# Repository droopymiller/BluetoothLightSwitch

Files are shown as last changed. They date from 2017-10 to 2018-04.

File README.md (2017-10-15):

# BluetoothLightSwitch
This project includes code and a schematic to make a bluetooth opperated light switch.
It accomplishes this using the Arduino Nano and HM-10

Because the HM-10 I had was actually a CC41-A, the "BRK" pin doesn't exist.
This lead me to connect the bluetooth module's VCC to an output on the Arduino so that it could be power cycled in order to disconnect clients

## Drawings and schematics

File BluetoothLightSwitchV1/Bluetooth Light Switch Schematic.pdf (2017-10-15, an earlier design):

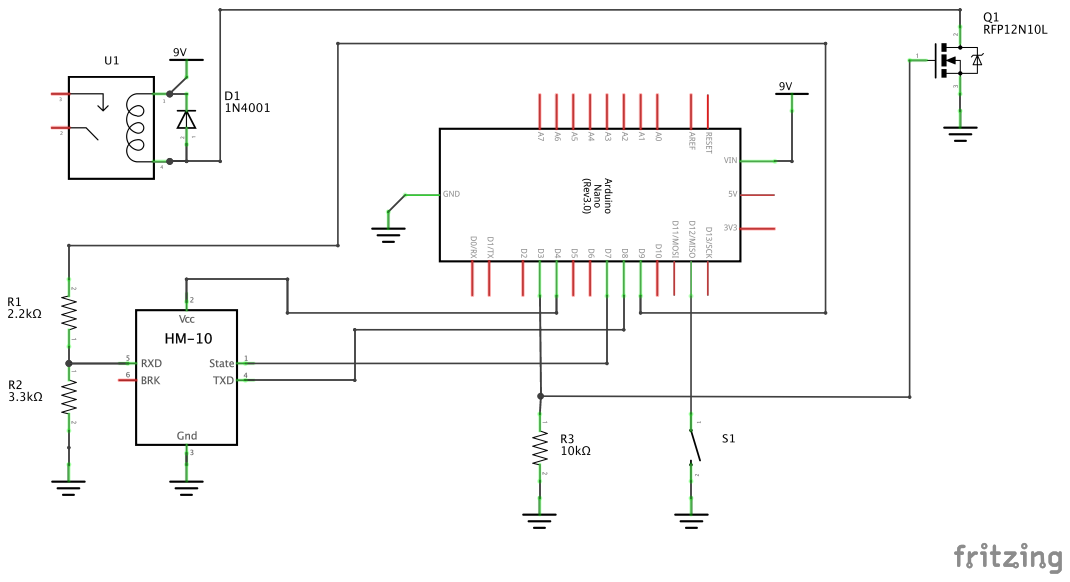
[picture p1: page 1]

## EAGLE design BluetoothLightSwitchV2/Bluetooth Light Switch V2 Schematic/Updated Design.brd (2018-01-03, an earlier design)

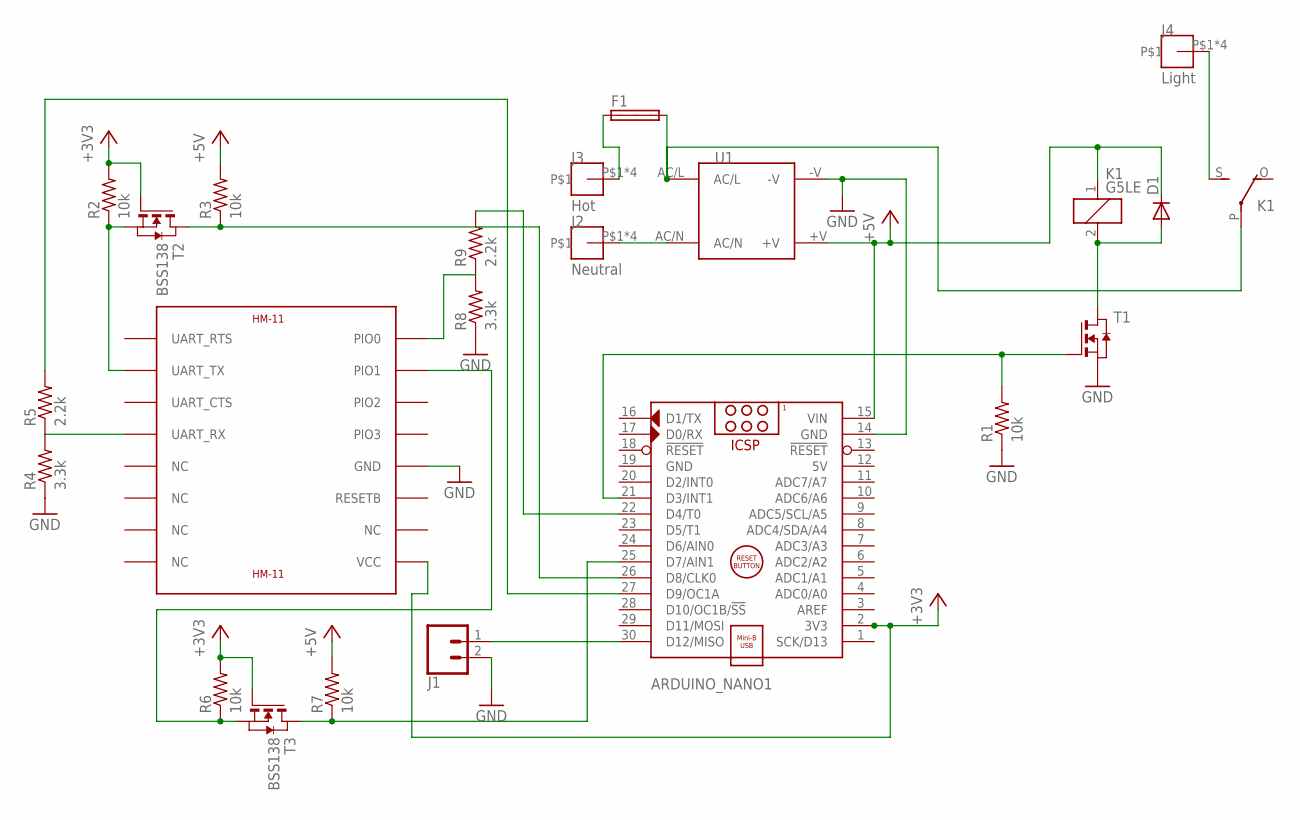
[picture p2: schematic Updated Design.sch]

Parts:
ARDUINO_NANO1: ARDUINO_NANO
D1: DIODE-SOD80C; SOD80C
F1: SHK20L
J1: CONN_025MM; SCREWTERMINAL-5MM-2
J2: Neutral; 7700
J3: Hot; 7700
J4: Light; 7700
K1: G5LE
R1, R2, R3, R6, R7: 10k; R0603
R4, R8: 3.3k; R0603
R5, R9: 2.2k; R0603
T1: NMOSSOT23; SOT-23
T2, T3: BSS138; SOT-23
U1: IRM-05-5; IRM-05
U$1: HM-11

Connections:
5V: ARDUINO_NANO1.12 (5V)
+3V3: ARDUINO_NANO1.2 (3V3), R2.2, R6.2, T2.3 (G), T3.3 (G), U$1.VCC
+5V: ARDUINO_NANO1.15 (VIN), D1.C, K1.1, R3.2, R7.2, U1.+V
GND: ARDUINO_NANO1.14 (GND), ARDUINO_NANO1.19 (GND), J1.2, U1.-V, U$1.GND
unnamed: ARDUINO_NANO1.30 (D12/MISO), J1.1
unnamed: R4.2, U$1.UART_RX
unnamed: ARDUINO_NANO1.21 (D3/INT1), T1.3 (G)
unnamed: F1.2A, K1.P, U1.AC/L
unnamed: J2.P$1, J2.P$2, J2.P$3, J2.P$4, U1.AC/N
unnamed: J4.P$1, J4.P$2, J4.P$3, J4.P$4, K1.S
unnamed: ARDUINO_NANO1.27 (D9/OC1A), R5.2
unnamed: D1.A, K1.2, T1.1 (D)
unnamed: R2.1, T2.2 (S), U$1.UART_TX
unnamed: ARDUINO_NANO1.26 (D8/CLK0), R3.1, T2.1 (D)
unnamed: R6.1, T3.2 (S), U$1.PIO1
unnamed: ARDUINO_NANO1.25 (D7/AIN1), R7.1, T3.1 (D)
unnamed: ARDUINO_NANO1.22 (D4/T0), R9.2
unnamed: R8.2, U$1.PIO0
unnamed: F1.1A, J3.P$1, J3.P$2, J3.P$3, J3.P$4

Board: 2 copper layers, 22 parts (0 on the bottom side), 18 nets, no tracks yet.

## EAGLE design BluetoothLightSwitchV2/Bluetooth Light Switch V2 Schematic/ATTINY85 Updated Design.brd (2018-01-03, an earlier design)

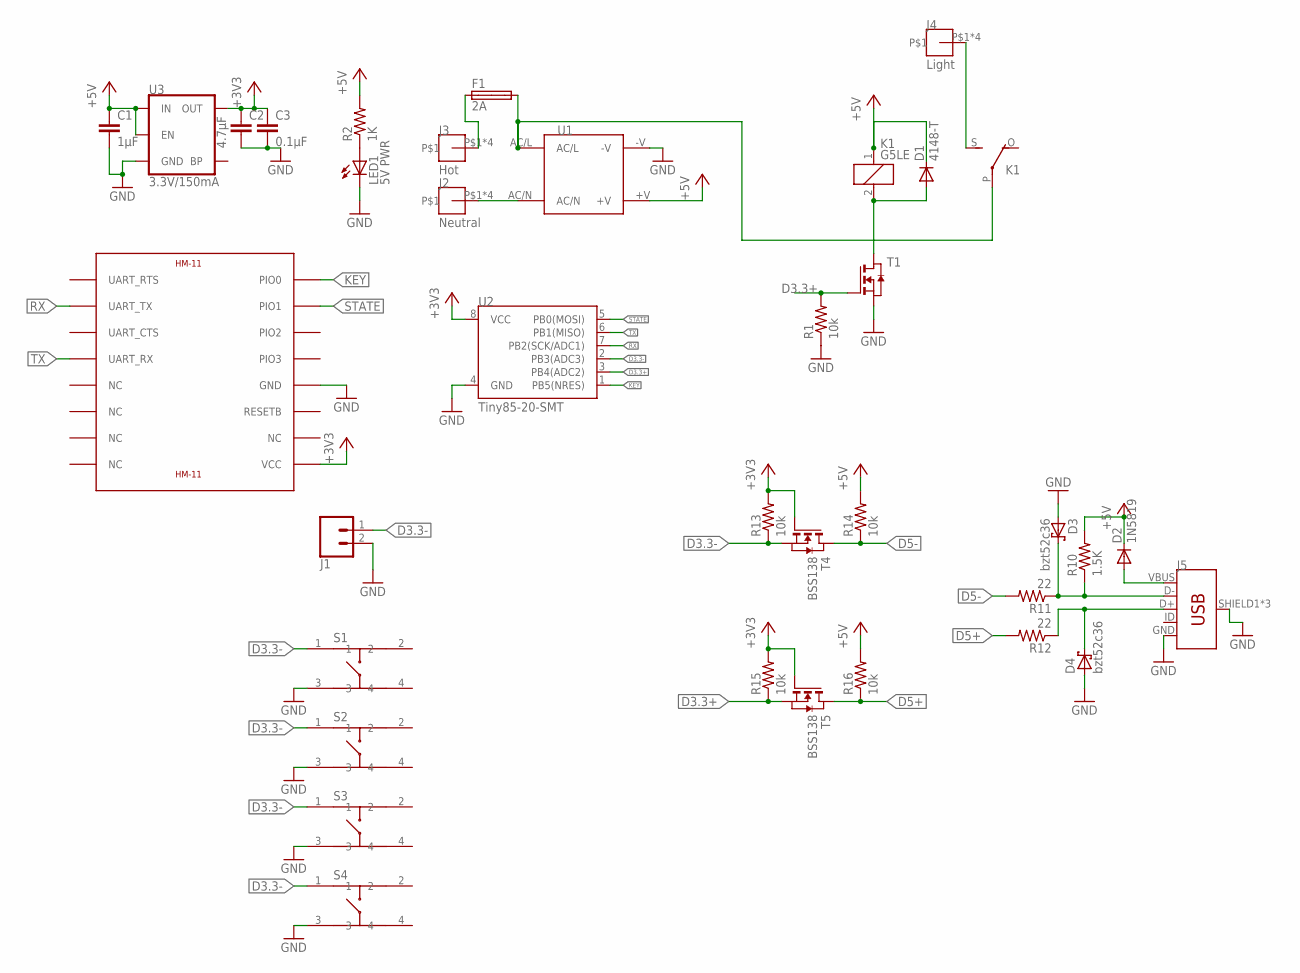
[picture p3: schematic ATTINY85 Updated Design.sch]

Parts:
C1: 1µF; C0603K
C2: 4.7µF; C0603K
C3: 0.1µF; C0603K
D1: 4148-T; SOD80C
D2: 1N5819; SOD323-R
D3, D4: bzt52c36; SOD323_ST
F1: 2A; SHK20L
J1: CONN_025MM; SCREWTERMINAL-5MM-2
J2: Neutral; 7700
J3: Hot; 7700
J4: Light; 7700
J5: USB_MICRO-B_FEMALE-SMT; USB-B-MICRO-SMD
K1: G5LE
LED1: 5V PWR; CHIPLED_0603
R1, R13, R14, R15, R16: 10k; R0603
R2: 1K; R0603
R10: 1.5K; R0603
R11, R12: 22; R0603
S1, S2, S3, S4: PTS645S_SMTR92; SMT
T1: NMOSSOT23; SOT-23
T4, T5: BSS138; SOT-23
U1: IRM-05-5; IRM-05
U2: Tiny85-20-SMT; SO08-EIAJ_MCU
U3: 3.3V/150mA; SOT23-5
U$1: HM-11

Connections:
+3V3: C2.1, C3.1, R13.2, R15.2, T4.3 (G), T5.3 (G), U2.8 (VCC), U3.5 (OUT), U$1.VCC
+5V: C1.1, D1.C, D2.C, K1.1, R2.2, R10.2, R14.2, R16.2, U1.+V, U3.1 (IN), U3.3 (EN)
D3.3+: R1.2, R15.1, T1.3 (G), T5.2 (S), U2.3 (PB4(ADC2))
D3.3-: J1.1, R13.1, S1.1, S2.1, S3.1, S4.1, T4.2 (S), U2.2 (PB3(ADC3))
D5+: R12.2, R16.1, T5.1 (D)
D5-: R11.2, R14.1, T4.1 (D)
GND: C1.2, C2.2, C3.2, D3.A, D4.A, J1.2, J5.GND, J5.SHIELD1 (SHIELD), J5.SHIELD2 (SHIELD), J5.SHIELD3 (SHIELD), LED1.C, R1.1, S1.3, S2.3, S3.3, S4.3, T1.2 (S), U1.-V, U2.4 (GND), U3.2 (GND), U$1.GND
HOT: F1.1A, J3.P$1, J3.P$2, J3.P$3, J3.P$4
KEY: U2.1 (PB5(NRES)), U$1.PIO0
LIGHT: J4.P$1, J4.P$2, J4.P$3, J4.P$4, K1.S
unnamed: LED1.A, R2.1
unnamed: F1.2A, K1.P, U1.AC/L
unnamed: D1.A, K1.2, T1.1 (D)
unnamed: D2.A, J5.VBUS
unnamed: D3.C, J5.D-, R10.1, R11.1
unnamed: D4.C, J5.D+, R12.1
NEUTRAL: J2.P$1, J2.P$2, J2.P$3, J2.P$4, U1.AC/N
RX: U2.7 (PB2(SCK/ADC1)), U$1.UART_TX
STATE: U2.5 (PB0(MOSI)), U$1.PIO1
TX: U2.6 (PB1(MISO)), U$1.UART_RX

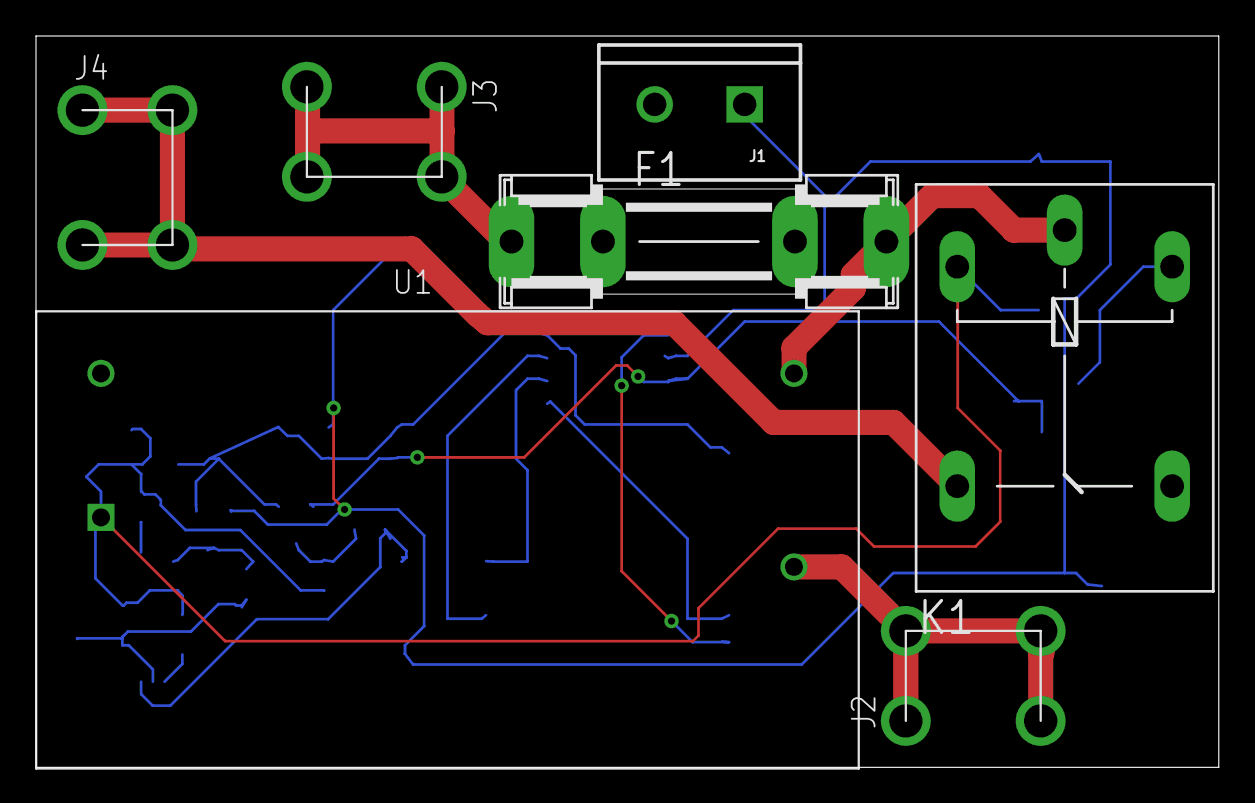
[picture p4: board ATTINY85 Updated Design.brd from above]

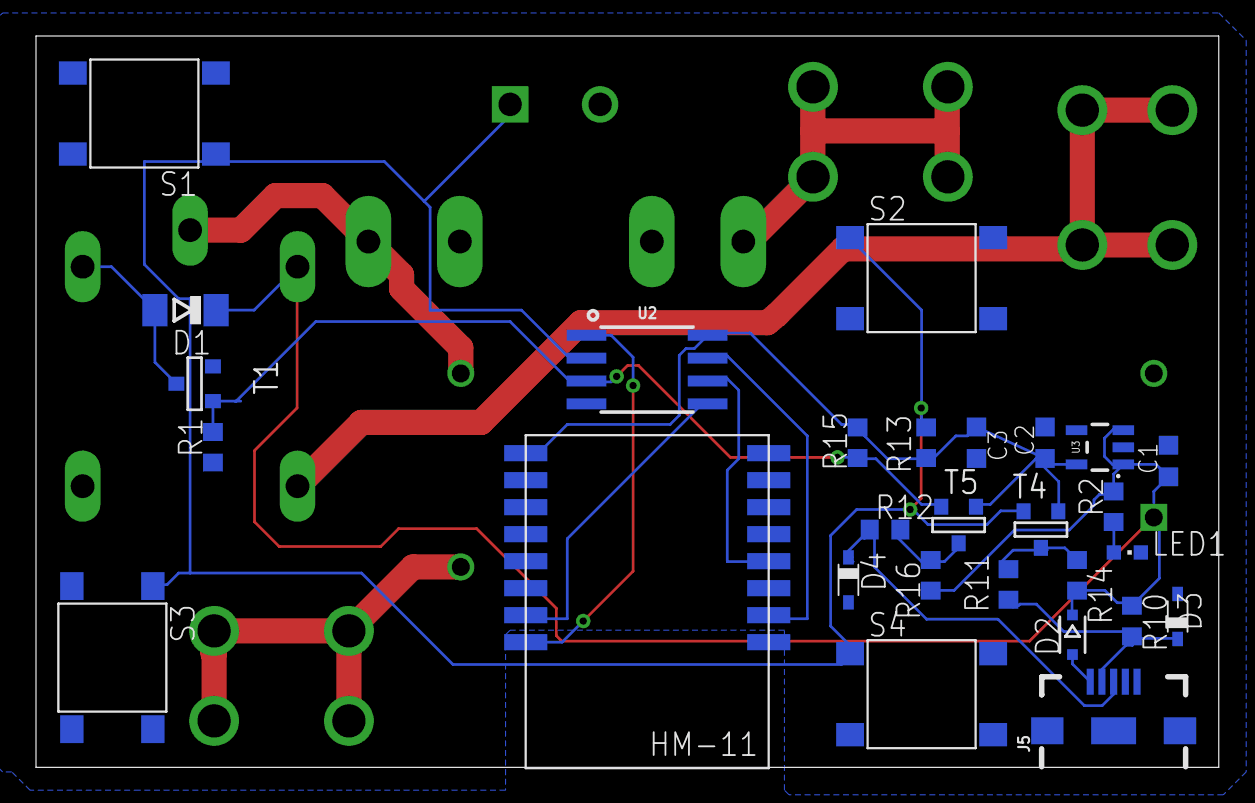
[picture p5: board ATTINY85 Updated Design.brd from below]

Board: 2 copper layers, 65.7 x 40.6 mm, 35 parts (28 on the bottom side), 20 nets.

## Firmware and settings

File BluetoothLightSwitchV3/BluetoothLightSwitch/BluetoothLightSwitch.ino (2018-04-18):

#include <SoftwareSerial.h>

#define HM10_PWR_PIN 4 //Used to turn HM-10 on and off, used to disconnect current clients
#define RELAY_PIN 3 //Used to control the relay
#define SWITCH_PIN 12 //Input for switch

// HM-10 module pins
#define STATE_PIN 7
#define RX_PIN 8
#define TX_PIN 9
SoftwareSerial mySerial(RX_PIN, TX_PIN); // RX, TX

boolean lightState = false;
char password[21] = "PWD1\r";
char debugPWD[21] = "DEBUG1\r";

const byte numChars = 32;
char receivedChars[numChars]; // an array to store the received data
boolean newData = false; //Variable for if a new line of data has been receive
boolean switchState; //Current State of button
boolean actuated = false; //True when timer has been set
boolean buttonDown = false; //Used to determine if button has been debounced
boolean disconnectInit = false; //If HM-10 power cycle has been initiated
boolean debug_Mode = false; //Used to keep track of if in debug mode.  Debug mode doesn't automatically disconnect
boolean previousBluetoothState; //Used to keep track of if HM-10 previously had a connection
boolean connectionTimerSet = false; //Used to determine if connection timer has been set
boolean disconnectTimerSet = false; //Used to determine if the disconnect timer has been set

unsigned long disconnectMillis; //Used for power cycling the HM-10
unsigned long previousMillis; //Used for debouncing switch
unsigned long connectionTimer; //Used to wait for connection to give status
unsigned long disconnectTimer; //Used to wait until bluetooth serial messages have been sent before disconnecting

const int debounceInt = 3; //Debounce interval for switch
const int powerCycleTime = 150; //Time (ms) that HM-10 is turned off for in order to remove power
const int connectionTime = 200; //Wait interval before sending status upon connection
const int disconnectTime = 200; //Wait interval before disconnection

void setup() {
  Serial.begin(9600);
  while(!Serial) {
    ; // wait for serial port to connect.  Needed for native USB port only
  }

  mySerial.begin(9600);
  //Declare outputs
  pinMode(HM10_PWR_PIN, OUTPUT);
  pinMode(RELAY_PIN, OUTPUT);
  //Declare inputs
  pinMode(SWITCH_PIN, INPUT);
  pinMode(STATE_PIN, INPUT);
  
  digitalWrite(SWITCH_PIN, HIGH); //Enable internal pullup resistor, reads LOW when closed
  digitalWrite(HM10_PWR_PIN, HIGH);

}

void loop() {
  relayState(); //Update relay state
  
  checkSwitch(); //Check to see if switch has been actuated
  
  serialInterface(); //Interface serial outputs

  checkConnection(); //Checks for bluetooth connection or disconnection
  
  recvWithEndMarker(); //Receive Data
  
  checkForPassword(); //Check Data for password
  
  bluetoothDisconnect(); //Check to see if bluetooth needs to be disconnected
}

//Interfaces USB serial to bluetooth serial
void serialInterface() {
  /*if (mySerial.available()) {
    Serial.write(mySerial.read());
  }*/
  if (Serial.available()) {
    mySerial.write(Serial.read()); 
  }
}

//Receives data with end of line marker
void recvWithEndMarker() {
  static byte ndx = 0;
  char endMarker = '\n';
  char rc;
 

  while (mySerial.available() > 0 && newData == false) {
    //Serial.write(mySerial.read());
    rc = mySerial.read();

    if (rc != endMarker) {
      receivedChars[ndx] = rc;
      ndx++;
      if (ndx >= numChars) {
        ndx = numChars - 1;
      }
    }
    else {
    receivedChars[ndx] = '\0'; // terminate the string
    ndx = 0;
    newData = true;
    }
  }
}

//Checks if password matches received data, resets newData
void checkForPassword() {
  if (newData) {
        //Print received data to serial and difference between password
        Serial.println(receivedChars);
        Serial.print("Difference: ");
        Serial.println(strcmp(receivedChars, password));
    if (strcmp(receivedChars, password) == 0) {
      changeLightState();
      if (lightState) {
        mySerial.write("Light Status: On\r\n");
      }
      else if (!lightState) {
        mySerial.write("Light Status: Off\r\n");
      }
      if (!debug_Mode) {
        mySerial.write("Disconnecting");
        disconnectInit = true;
      }
    }
    else if (strcmp(receivedChars, debugPWD) == 0) {
      debug_Mode = !debug_Mode;
      if (debug_Mode) {
        mySerial.write("Entering debug mode\r\n");
      }
      else if (!debug_Mode) {
        mySerial.write("Exiting debug mode\r\n");
      }
    }
    else{
      mySerial.write("Incorrect Password\r\n");
    }
  }
  newData = false;
}


void bluetoothDisconnect() {
  if (disconnectInit && !disconnectTimerSet) {
    disconnectTimer = millis();
    disconnectTimerSet = true;
  }
  if (disconnectTimerSet && ((millis() - disconnectTimer) >= disconnectTime)){
    disconnectTimerSet = false;
    disconnectInit = false;
    disconnectMillis = millis();
  }
  if (((millis() - disconnectMillis) < powerCycleTime) && ((millis() - disconnectMillis) >= 0)) {
    digitalWrite(HM10_PWR_PIN, LOW);
  }
  else if ((millis() - disconnectMillis) < 0) {
    disconnectMillis = millis();
  }
  else {
    digitalWrite(HM10_PWR_PIN, HIGH);
  }
}

//Changes lightState when called
void changeLightState() {
  lightState = !lightState;
  //digitalWrite(13, lightState);
}

//Switch relay based on lightState
void relayState() {
  digitalWrite(RELAY_PIN, lightState);
}

void checkSwitch() {
  switchState = digitalRead(SWITCH_PIN);
  if (!switchState) {
    if (!actuated) {
      previousMillis = millis();
      actuated = true;
    }
    if ((millis() - previousMillis >= debounceInt) && actuated && !buttonDown) {
      changeLightState();
      buttonDown = true;
    }
  }
  if (switchState && (millis() - previousMillis >= debounceInt)) {
    actuated = false;
    buttonDown = false;
  }
}

void checkConnection() {
  if(previousBluetoothState && !digitalRead(STATE_PIN)){
    debug_Mode = false; //Reset debug mode if client disconnects
  }
  else if(!previousBluetoothState && digitalRead(STATE_PIN)) {
    connectionTimer = millis();
    connectionTimerSet = true;
  }
  if (connectionTimerSet && ((millis() - connectionTimer) >= connectionTime)){
      connectionTimerSet = false;
      if (lightState) {
        mySerial.write("Light Status: On\r\n");
      }
      else {
        mySerial.write("Light Status: Off\r\n");
      }
    }
  previousBluetoothState = digitalRead(STATE_PIN);
}

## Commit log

2017-10-07 Start of Arduino file, Added .gitignore to ignore mac files
2017-10-07 Bluetooth functionality is complete, no switch functionality
2017-10-07 Added schematic image
2017-10-08 Switch is functional
2017-10-15 Fixed debounce function Added disconnect function (disconnect client from HM-10 after receiving instruction by power cycling HM-10) Added debug mode (Client is not automatically disconnected)
    [BluetoothLightSwitch.ino]
2017-10-15 Added Fritzing Schematic, removed hand drawn schematic
    [Bluetooth Light Switch Schematic.fzz]
2017-10-15 Removed "Part 1", "Part 2" labels
    [Bluetooth Light Switch Schematic.fzz]
2018-01-03 Separated Original Design (V1) from Updated Design (V2)
    [ATTINY85 Updated Design Extended Board.brd, ATTINY85 Updated Design Extended Board.sch, ATTINY85 Updated Design.brd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]

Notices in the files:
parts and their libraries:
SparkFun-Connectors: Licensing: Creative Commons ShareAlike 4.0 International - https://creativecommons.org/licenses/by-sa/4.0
